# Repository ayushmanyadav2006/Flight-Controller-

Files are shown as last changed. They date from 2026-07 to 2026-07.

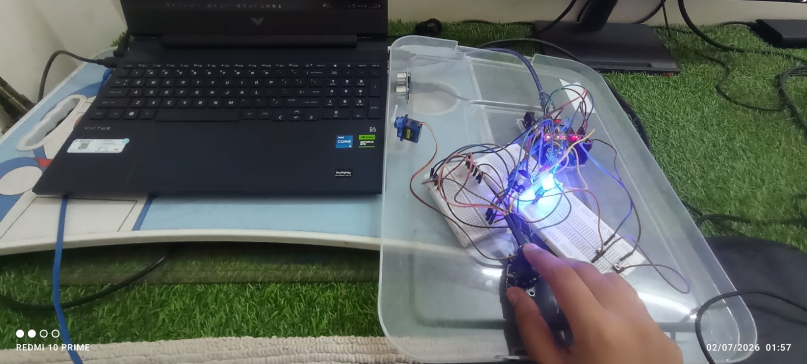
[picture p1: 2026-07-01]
Control Electronics Hardware.jpg

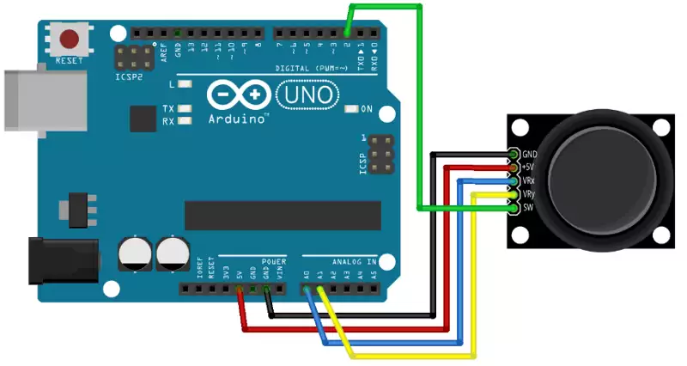
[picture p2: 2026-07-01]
Joystick to Arduino.webp

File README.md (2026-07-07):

# Flight-Controller-

Created a electronic control hardware to control the roll, pitch, yaw of a airplane
Also the speed of the airplane, landing gears etc

The electronics consists of 
Arduino Uno (Microcontroller board) 
Joystick (Controlling the roll and pitch)
Potentiometer (Controlling the speed of the airplane)
Buttons (Controlling the yaw of the airplane) 
Joystick button (Controlling the landing gear) 

All the connections were made on breadboard by using jumper wires

I also made the PCB for the samne breadboard electronics.

Working video link: https://www.youtube.com/watch?v=8yyL5-LtBI4&t=84s

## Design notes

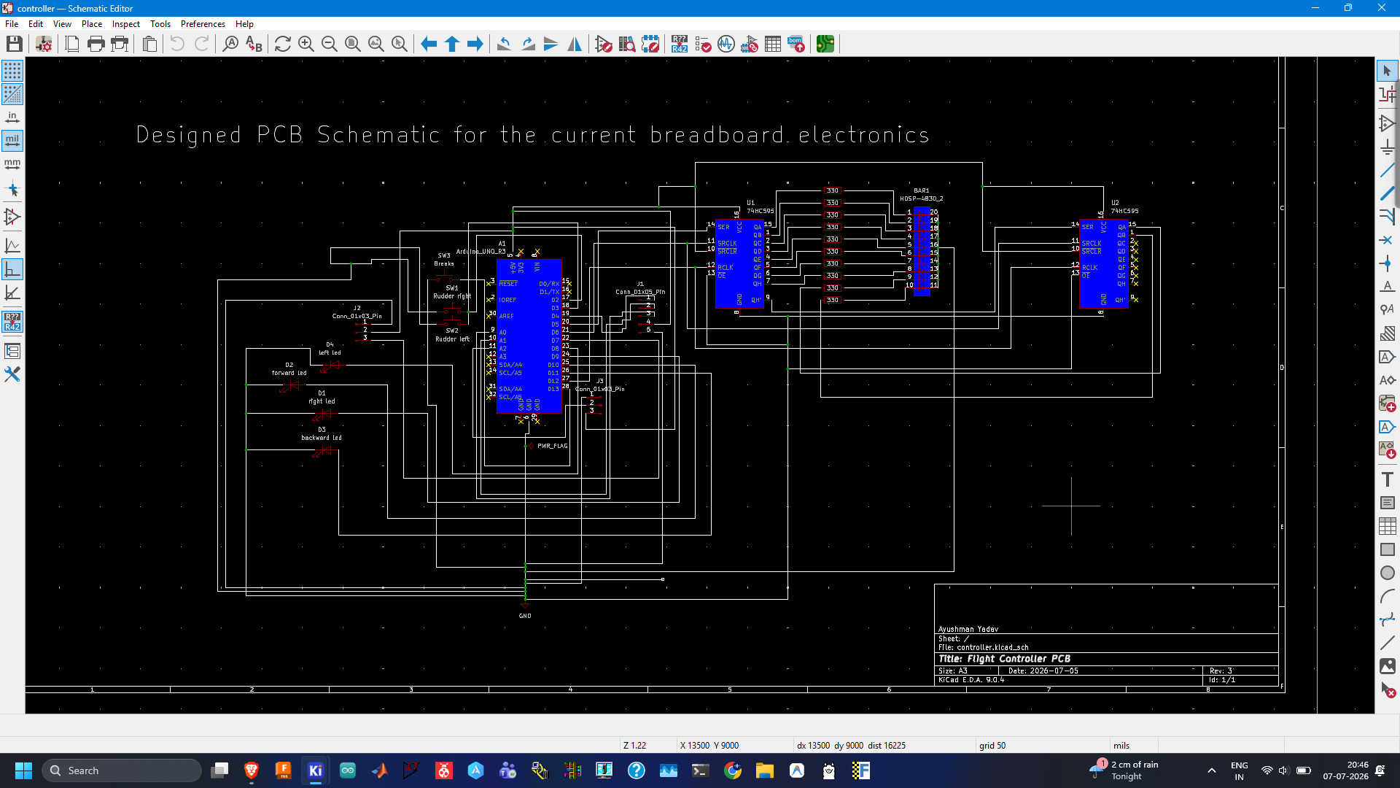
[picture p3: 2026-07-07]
Flight Controller Schematic.png

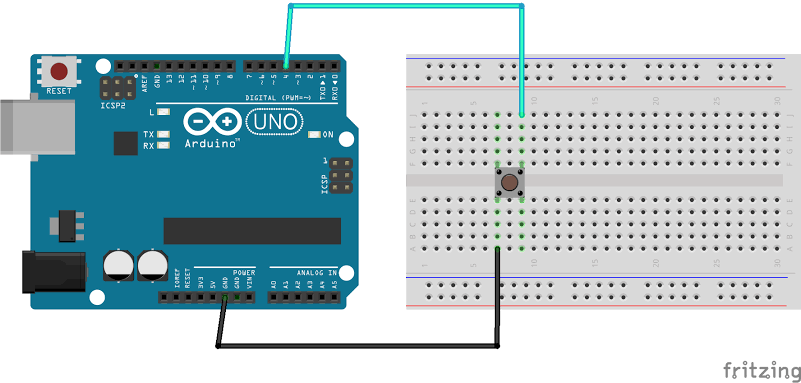
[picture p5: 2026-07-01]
Button to Arduino.png

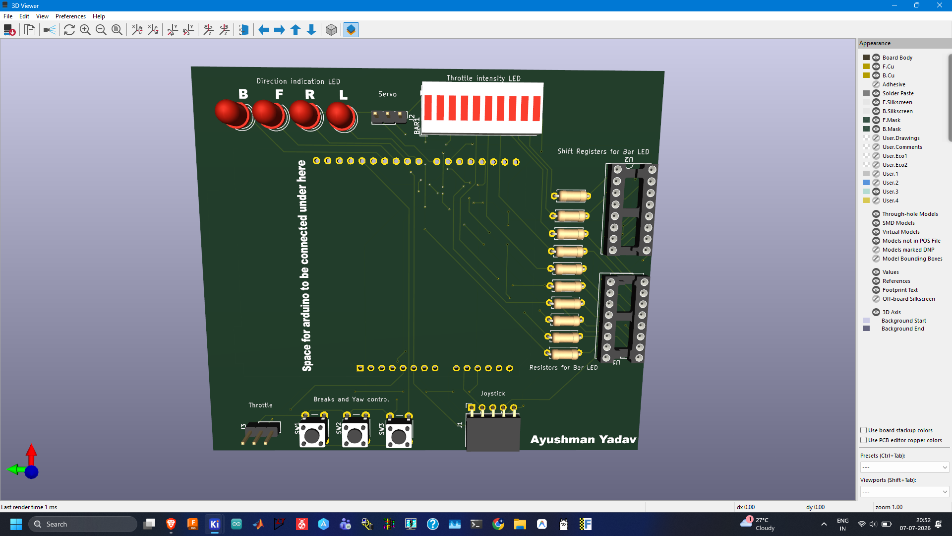
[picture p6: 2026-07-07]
Flight Controller PCB.png

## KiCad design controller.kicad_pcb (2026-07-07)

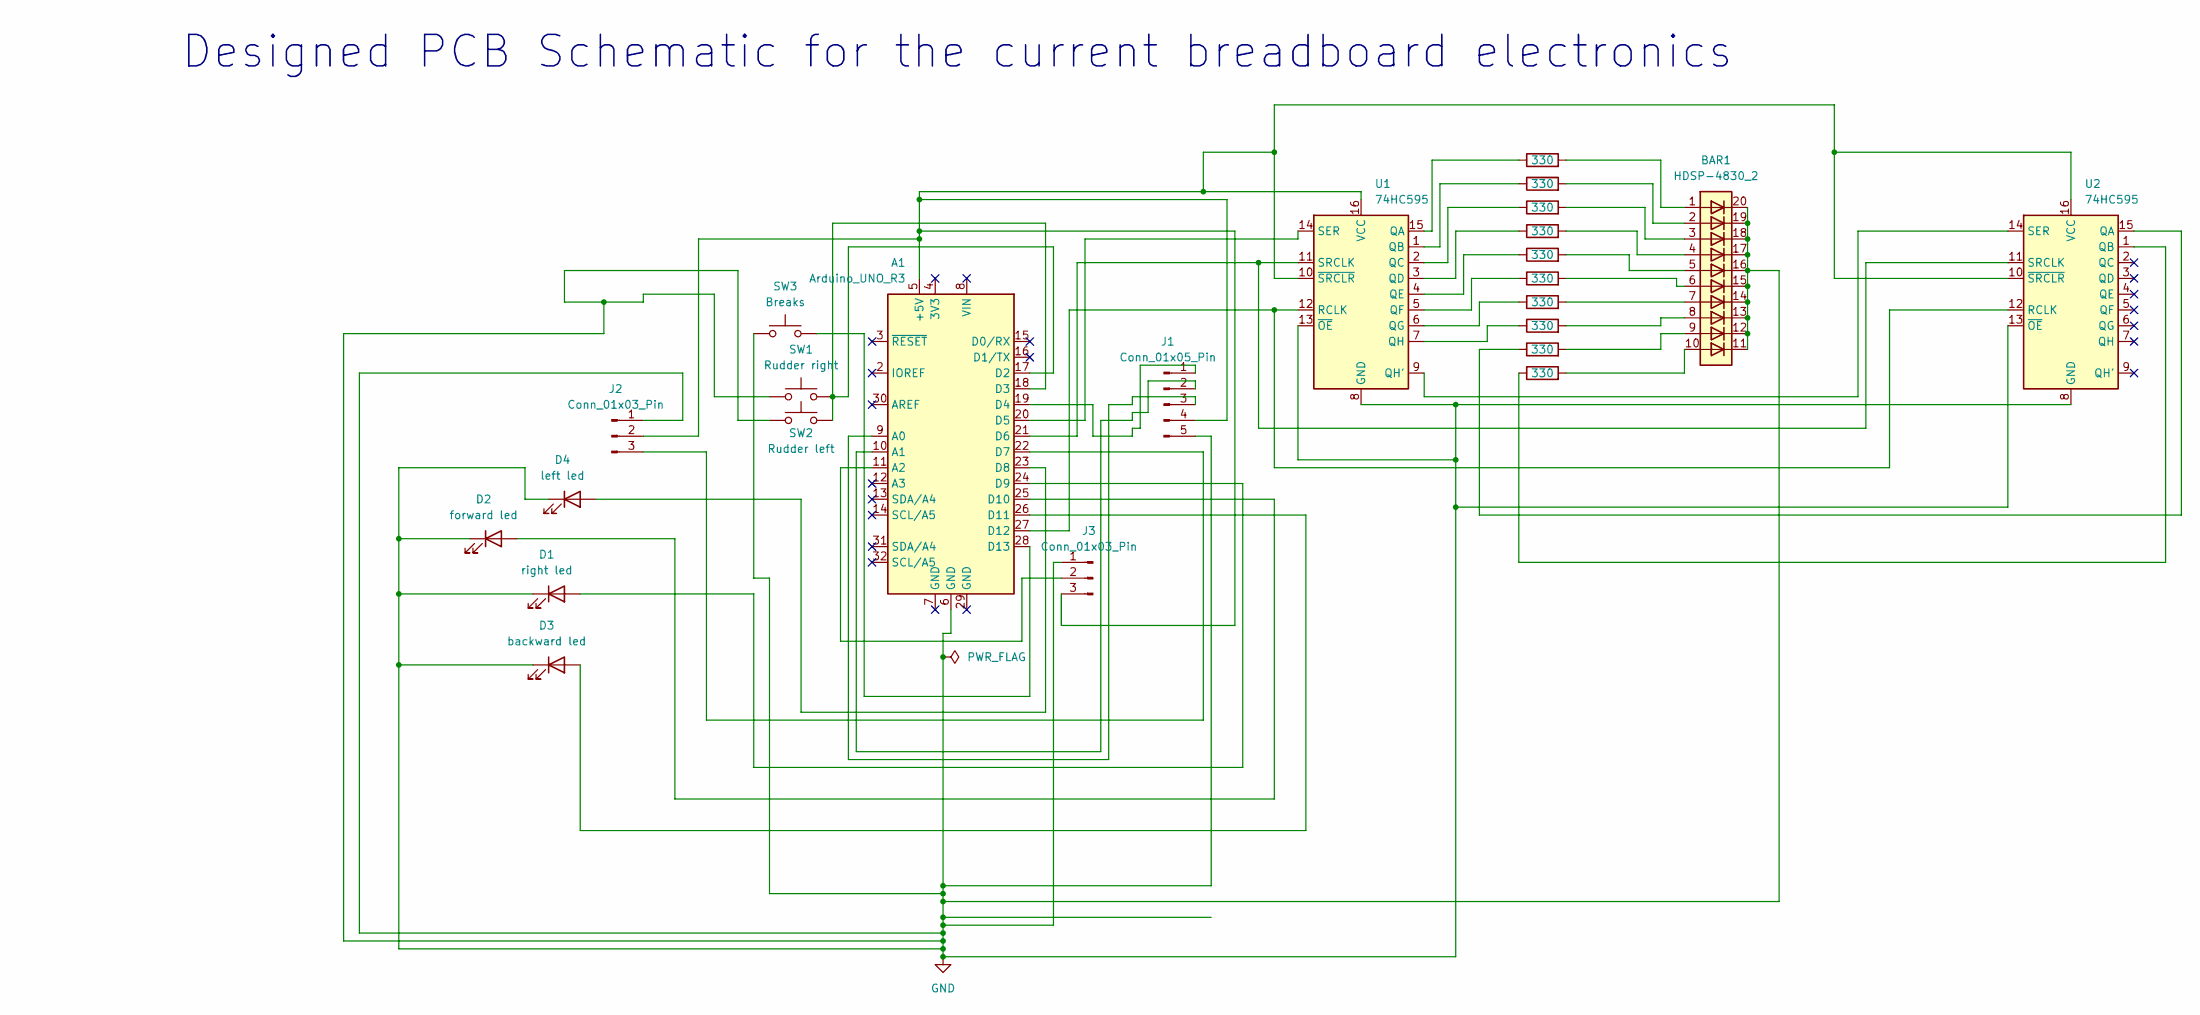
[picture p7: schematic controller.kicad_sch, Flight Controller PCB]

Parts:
A1: Arduino_UNO_R3
BAR1: HDSP-4830_2; HDSP-4830
D1: right led; LED_D5.0mm
D2: forward led; LED_D5.0mm
D3: backward led; LED_D5.0mm
D4: left led; LED_D5.0mm
J1: Conn_01x05_Pin; PinSocket_1x05_P2.54mm_Horizontal
J2, J3: Conn_01x03_Pin; PinHeader_1x03_P2.54mm_Vertical
R1, R2, R3, R4, R5, R6, R7, R8, R9, R10: 330; R_Axial_DIN0207_L6.3mm_D2.5mm_P7.62mm_Horizontal
SW1: Rudder right; SW_PUSH_6mm
SW2: Rudder left; SW_PUSH_6mm
SW3: Breaks; SW_PUSH_6mm
U1, U2: 74HC595; DIP-16_W7.62mm_Socket

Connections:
GND: A1.6 (GND), BAR1.11 (K), BAR1.12 (K), BAR1.13 (K), BAR1.14 (K), BAR1.15 (K), BAR1.16 (K), BAR1.17 (K), BAR1.18 (K), BAR1.19 (K), BAR1.20 (K), D1.1 (K), D2.1 (K), D3.1 (K), D4.1 (K), J1.5, J2.1, J3.1, SW1.1, SW2.1, SW3.1, U1.8 (GND), U1.13 (~OE), U2.8 (GND), U2.13 (~OE)
unnamed: A1.5 (+5V), J1.4, J2.2, J3.3, U1.10 (~SRCLR), U1.16 (VCC), U2.10 (~SRCLR), U2.16 (VCC)
unnamed: A1.9 (A0), J1.3
unnamed: A1.10 (A1), J1.2
unnamed: A1.11 (A2), J3.2
unnamed: A1.17 (D2), A1.18 (D3), SW1.2, SW2.2
unnamed: A1.19 (D4), J1.1
unnamed: A1.20 (D5), U1.14 (SER)
unnamed: A1.21 (D6), U1.11 (SRCLK), U2.11 (SRCLK)
unnamed: A1.22 (D7), J2.3
unnamed: A1.23 (D8), D4.2 (A)
unnamed: A1.24 (D9), D1.2 (A)
unnamed: A1.25 (D10), D2.2 (A)
unnamed: A1.26 (D11), D3.2 (A)
unnamed: A1.27 (D12), U1.12 (RCLK), U2.12 (RCLK)
unnamed: A1.28 (D13), SW3.2
unnamed: BAR1.1 (A), R1.2
unnamed: BAR1.2 (A), R2.2
unnamed: BAR1.3 (A), R3.2
unnamed: BAR1.4 (A), R4.2
unnamed: BAR1.5 (A), R5.2
unnamed: BAR1.6 (A), R6.2
unnamed: BAR1.7 (A), R7.2
unnamed: BAR1.8 (A), R8.2
unnamed: BAR1.9 (A), R9.2
unnamed: BAR1.10 (A), R10.2
unnamed: R1.1, U1.15 (QA)
unnamed: R2.1, U1.1 (QB)
unnamed: R3.1, U1.2 (QC)
unnamed: R4.1, U1.3 (QD)
unnamed: R5.1, U1.4 (QE)
unnamed: R6.1, U1.5 (QF)
unnamed: R7.1, U1.6 (QG)
unnamed: U1.9 (QH'), U2.14 (SER)
unnamed: R8.1, U1.7 (QH)
unnamed: R9.1, U2.15 (QA)
unnamed: R10.1, U2.1 (QB)

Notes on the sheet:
Designed PCB Schematic for the current breadboard electronics

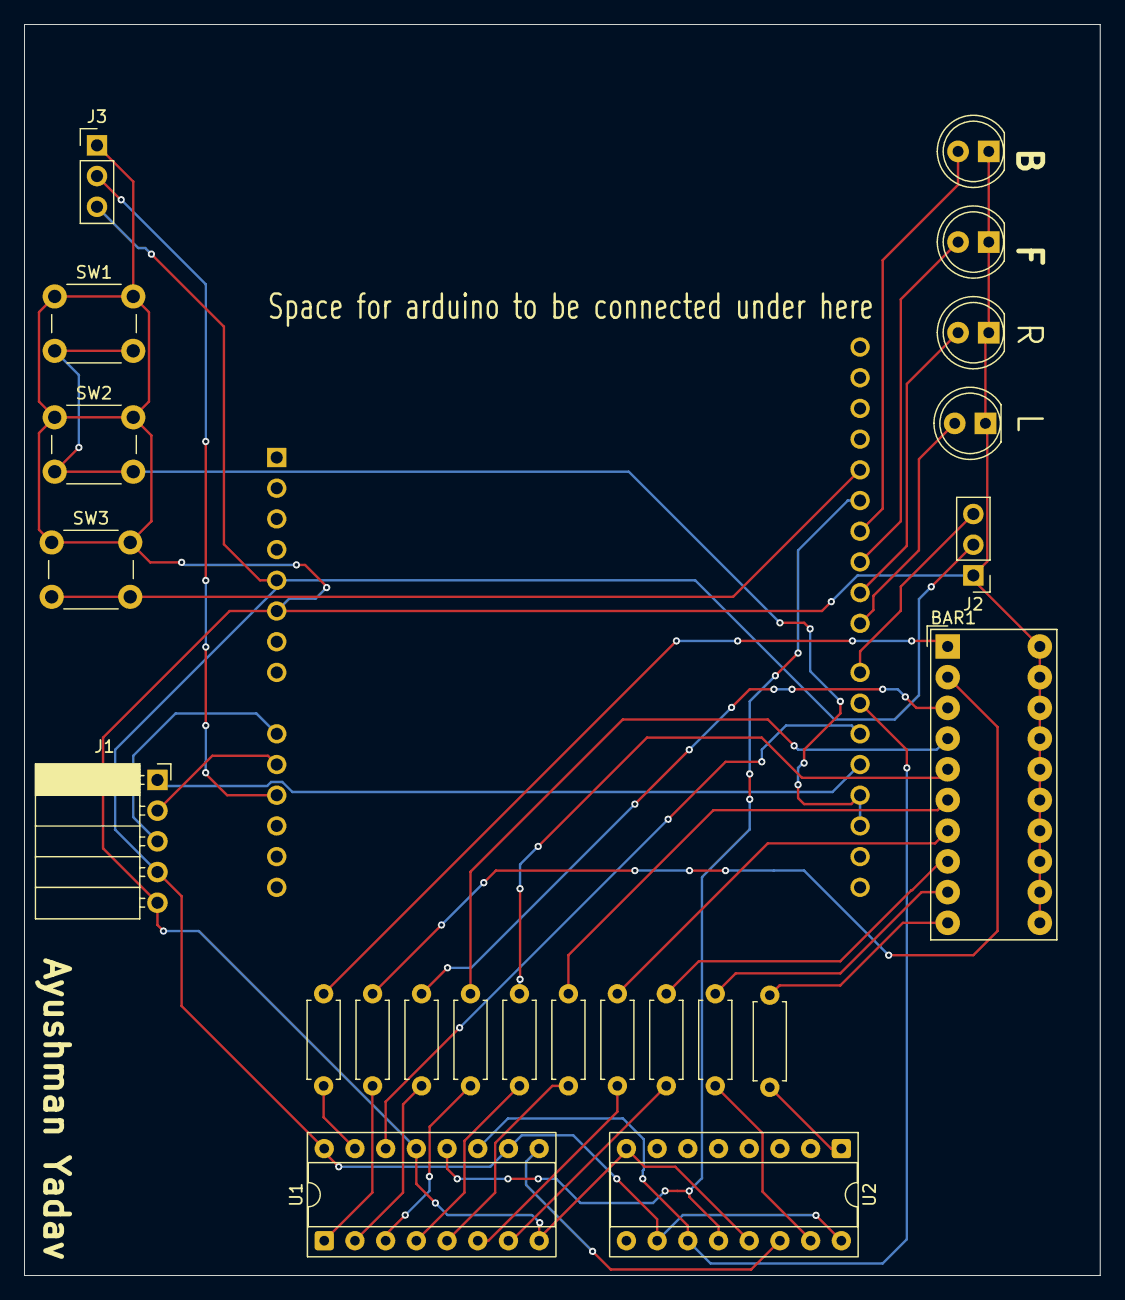
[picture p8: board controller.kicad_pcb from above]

Board: 2 copper layers, 89.0 x 103.5 mm, 24 parts (1 on the bottom side), 37 nets.

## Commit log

2026-07-01 Add initial joystick and servo control code
    This is the arduino code to control all the breadboard electronics before interfacing it to the game
2026-07-01 Fix rudder control logic in main code
    All other things are working but the rudder is bent towards left, I need to fix that
2026-07-01 Create Python Bride File
    Bridges the data from Adruino serial to Flight Gear controls
2026-07-03 Create Code with flaps due
    Flaps won't be implemented, I need to implement breaks instead of flaps but I dont have an additional button
